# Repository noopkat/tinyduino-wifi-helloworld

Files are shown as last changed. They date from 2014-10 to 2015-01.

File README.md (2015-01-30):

tinyduino-wifi-helloworld
=========================

example IoT project for developers new to wifi driven hardware 

knoll

## Ok, whut.
This is just a quick project showing how simple it is to get up and running with the latest hotness - Internet of Thingy-ma-jiggers.

When all assembled and placed in a mailbox, it'll connect via wifi to both email and sms you when you get mail!

## I do not understand how.
In this example, I'm using an Arduino microprocessor teamed with a light sensor and a wifi module. A battery powers the Arduino, which constantly keeps track of how much light is in the mailbox. When the USPS dudette/dude opens the little back door to put your mail and parcels in, light streams into the mailbox. This trips the device, which will then connect to wifi and send the email and sms to you.

If you do not have one of those door opening mailboxes, you can program it the opposite way - put it in your mailbox so that the sensor gathers light from the mail slot, and when envelopes are pushed through it blocks the light momentarily. Effectively that will be the trigger.

Yep, this only works in daylight, but it's pretty cool anyway. YMMV with wifi strength if your mailbox is made of metal.

## Disclaimer
**This example is presented as educational only.**

Postal companies might not be too pleased about spotting a mysterious device in a mailbox. They won't always assume it's a perfectly harmless Internet of Thingy-ma-flippers contraption full of awesome. **I am not condoning breaking the law with this project. Make sure you're familar with mail/mailbox tampering laws in your country**. The U.S., for example, has a helpful PDF on mail security you can [view here](https://www.hsdl.org/?view&did=34409). Spoiler alert: it has serious people holding guns on the front cover. [This poster is also pretty amazing](https://about.usps.com/securing-the-mail/mailtampering.htm).

Long story short - don't scare the willies out of your friendly neighbourhood post deliverer. Nobody wants the SWAT outside their house.

## Shopping list
+ [TinyCircuits Processor board](https://tiny-circuits.com/tinyduino-processor-board.html)
+ [TinyCircuits Wifi module](https://tiny-circuits.com/tiny-shield-wifi.html)
+ [TinyCurcuits Proto module](https://tiny-circuits.com/tiny-shield-proto-board-2.html) (any will do)
+ [TinyCircuits USB programmer module](https://tiny-circuits.com/tiny-shield-usb-and-icp.html) (not pictured)
+ micro USB cable
+ 10k Ohm resistor
+ [photocell resistor](http://www.adafruit.com/products/161)
+ [3.7v LiPo battery](http://www.adafruit.com/products/1578), at least 500mA 

Tools I assume you have already:
+ [LiPo charger](http://www.adafruit.com/products/1304)
+ soldering iron
+ solder
+ good eyes (my eyes are terrible for close-up work like soldering, but I still manage okay)

## Assembly
[Read this, taken from my article in NDC Magazine](https://github.com/noopkat/tinyduino-wifi-helloworld/blob/master/article.md)

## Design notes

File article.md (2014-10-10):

# Using the Arduino platform to create your very own IoT devices
As a software developer, there's something magic about being able to say, "I made this myself!". Building hardware to integrate with software is no different. Sure, you can buy off the shelf IoT devices for your home and lifestyle, but there's much more fun in building your own. You'll learn a lot about how they work, and will take away a sense of pride and achievement.

This is just a quick project showing how simple it is to get up and running with building and programming your own Internet of Things devices.
When all assembled and placed in a mailbox, this contraption will connect via WiFi to both email and SMS you when you get mail!

In this example, I'm using an Arduino microprocessor teamed with a light sensor and a WiFi module. A battery powers the Arduino, which constantly keeps track of how much light is in the mailbox. When the postal delivery opens the little back door to put your mail and parcels in, light streams into the mailbox. This trips the device, which will then connect to WiFi and send the email and SMS to you.

If you do not have one of those door opening mailboxes, you can program it the opposite way - put it in your mailbox so that the sensor gathers light from the mail slot, and when envelopes are pushed through it blocks the light momentarily. Effectively that will be the trigger.

This only works in daylight, but it's pretty cool anyway. Your mileage may vary with WiFi strength if your mailbox is made of metal.

The full code is hosted on Github: https://github.com/noopkat/tinyduino-wifi-helloworld

**Warning**  - postal companies might not be too pleased about spotting a mysterious device in a mailbox. They won't always assume it's a perfectly harmless Internet of Things device. I am not condoning breaking the law with this project. Make sure you're familiar with mail/mailbox tampering laws in your country. Long story short - don't scare your friendly neighbourhood post deliverer. Nobody wants the police outside their house!

knoll of parts

## Shopping list
+ [TinyCircuits Processor board](https://tiny-circuits.com/tinyduino-processor-board.html)
+ [TinyCircuits Wifi module](https://tiny-circuits.com/tiny-shield-wifi.html)
+ [TinyCurcuits Proto module](https://tiny-circuits.com/tiny-shield-proto-board-2.html) (any will do)
+ [TinyCircuits USB programmer module](https://tiny-circuits.com/tiny-shield-usb-and-icp.html) (not pictured)
+ micro USB cable
+ 10k Ohm resistor
+ [photocell resistor](http://www.adafruit.com/products/161)
+ [3.7v LiPo battery](http://www.adafruit.com/products/1578), at least 500mA 

Tools I assume you have already:
+ [LiPo charger](http://www.adafruit.com/products/1304)
+ soldering iron
+ solder
+ good eyes (my eyes are terrible for close-up work like soldering, but I still manage okay)

## Assembly
My favourite feature of the TinyCircuits system (other than the tiny size) is the way they easily click together to supply the technology you need.
First, we're going to click everything together as we need it. 

Take the processor board, and click the USB module to the top of it. Then, click the WiFi module to the top of the USB one. Lastly, click together the proto board to the very top of the stack. This will be the order of the stack when we develop it. It allows us to power the board without a battery via the computer, and we can also program it this way.

Next, remove the proto module from the top of the stack. Solder the resistor and photocell to it. The resistor goes from A0 to GND, and the photocell shares the A0, and the other end goes to VBATT. VBATT is a special pin that makes both the USB and battery power sources available to use. See the breadboard fritzing diagram below to assist you:

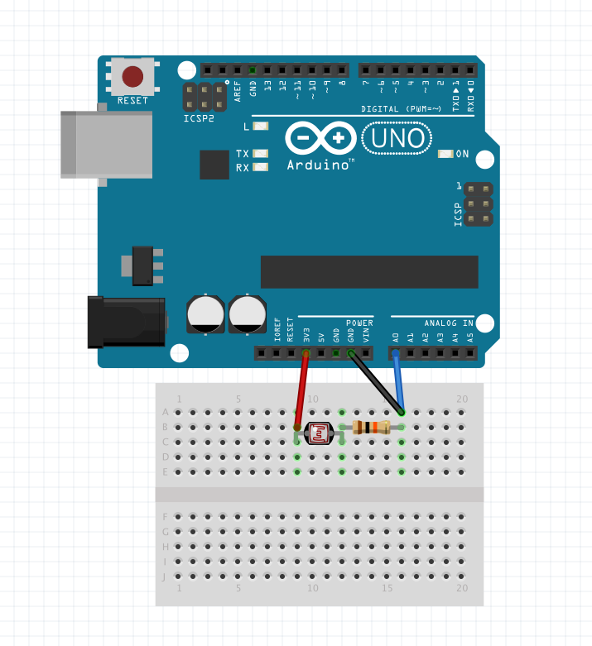
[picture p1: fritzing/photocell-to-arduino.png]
fritzing breadboard


See the following example for how it will look when complete. Note I have left the component arms rather long so that it's easier to see what's going on.

photo of stack

## Upload Arduino code
Click the proto module back onto your TinyCircuit stack. Plug a micro USB cable into the programming board, then connect to your computer. In the Arduino software, set the board to 'Arduino Pro Mini 3.3v w/ ATMega 328'. Open the sketch from the repo and click 'upload'. Select the correct USB device if prompted.

The main loop of the sketch is pretty simple, see the truncated code below:

```c++
uint32_t ip = cc3000.IP2U32(10,0,1,4);
int port = 8081;
String path = "/mailbox/token/";
String token = "558822";
String request = "GET " + path + token + " HTTP/1.0";

void loop(void)
{
  sensorValue = analogRead(sensorPin);
  // print to serial monitor for debugging purposes
  Serial.println(sensorValue);

  // if light source appears, set bright to true and send request
  // you may have the fiddle with this value to suit your light source
  if (sensorValue < 450 && bright == false) {
      // this will ensure request is sent only once
      bright = true;
      // send request to mailbox server
      send_request(request);
  } 

  // light source gone, go back to dark mode again
  if (sensorValue > 450 && bright == true) {
    bright = false;
  }
  
  delay(300);
}
```

You'll definitely need to play with the default light reading value set in the code above for best results with the physical place you're setting up your device in.

## Set up your server
I created a really simple NodeJS hapi server instance for dealing with the email and SMS. It is running on the local network the device is connected to via WiFi. The server simply waits for a GET request to the specified route, then verifies the request with a static token the Arduino will send as part of the request. This token should help stop your friends pranking you!

When the request is successful, the route handler will call some third party API's to send the notifications. I'm using Twilio for SMS, and Mailgun for the email.

A truncated sample of the code:

```javascript
var Hapi  = require('hapi');
var server = new Hapi.Server('10.0.1.4', 8081);
var passToken = '558822';

server.route({
    method: 'GET',
    path: '/mailbox/token/{token?}',
    handler: function (request, reply) {
      if (request.params.token && request.params.token === passToken) {
        // Twilio
        sendSMS();
        // MailGun
        sendEmail();
     // simple reply for testing manually
        reply('you\'ve got mail!');
      } else {
      // someone's being a prankster if missing/wrong token
        reply('why you gotta troll me, friend :(');
      }
    }
});
// Start the server
server.start();
```

Start the server in bash:

```
node index.js
```

## Test your device
While still plugged in to your computer, reset your device, and make sure your NodeJS server is running. To debug, watch both the Arduino app serial monitor's output, and your bash window. Play with the photo sensor, covering it up and then exposing it to light. You should start receiving emails and SMS's. 

Once verified, you can take the USB programming module out of your TinyCircuit stack completely, as we no longer need it. You'll see 2 terminals on the processor board. Solder a LiPo battery JST connector to these terminals in order to have this device run truly wire free and discreetly. Test again with the LiPo battery connected, then you're ready to use your finished device!

## Optional step
3D print a case for your new contraption, to make it look geek professional.

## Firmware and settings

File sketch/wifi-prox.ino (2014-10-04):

/* 
*  Tiny WiFi light sensor with a Tinyduino + CC3000 wifi module + photocell resistor
*  CC3000 lib written by Adafruit
*  sendRequest() method orginally written by Marco Schwartz for Open Home Automation
*  https://github.com/openhomeautomation/tiny-wifi-temperature/blob/master/tiny_weather_station/tiny_weather_station.ino
*  Further hacked by @noopkat for use with a light sensor, and a hard-set tokenised GET based on certain conditions, instead of constant reporting
*/

// Include required libraries
#include <Adafruit_CC3000.h>
#include <ccspi.h>
#include <SPI.h>
#include <string.h>
#include <stdlib.h>

// Define CC3000 chip pins
#define ADAFRUIT_CC3000_IRQ   2
#define ADAFRUIT_CC3000_VBAT  A3
#define ADAFRUIT_CC3000_CS    8

// WiFi network
#define WLAN_SSID       ""        // cannot be longer than 32 characters
#define WLAN_PASS       ""
#define WLAN_SECURITY   WLAN_SEC_WPA2 // This can be WLAN_SEC_UNSEC, WLAN_SEC_WEP, WLAN_SEC_WPA or WLAN_SEC_WPA2

// Create CC3000 instance
Adafruit_CC3000 cc3000 = Adafruit_CC3000(ADAFRUIT_CC3000_CS, ADAFRUIT_CC3000_IRQ, ADAFRUIT_CC3000_VBAT, SPI_CLOCK_DIV2);
                                         
// Local server IP, port, and repository (replace these with your own server setup)
uint32_t ip = cc3000.IP2U32(10,0,1,4);
int port = 8081;
String path = "/mailbox/token/";
String token = "558822";

// this is the api call (minus ip and port) to your software running anywhere
// token is just a little verification to prevent terrible friends just hitting your service to troll you with false positives
String request = "GET " + path + token + " HTTP/1.0";

int sensorPin = A0;
// set to dark to begin with
int sensorValue = 1023;
bool bright = false;


void setup(void)
{
  // Start serial
  Serial.begin(9600);
    
  // Initialise the CC3000 module
  if (!cc3000.begin())
  {
    while(1);
  }
}

void loop(void)
{
  sensorValue = analogRead(sensorPin);
  Serial.println(sensorValue);

  // if light source appears, set bright to true and send request
  if (sensorValue < 450 && bright == false) {
      // this will ensure request is sent only once
      bright = true;
      // connect to WIFI
      connect_wifi();
      // hit up mailbox server
      send_request(request);
      // disconnect to save battery
      cc3000.disconnect();
  } 

  // light source gone, go back to dark mode again
  if (sensorValue > 450 && bright == true) {
    bright = false;
  }
  
  delay(300);
}

void connect_wifi() {
  // Connect to  WiFi network
  cc3000.connectToAP(WLAN_SSID, WLAN_PASS, WLAN_SECURITY);
  Serial.println("Connected to WiFi network!");
    
  // Check DHCP
  Serial.println(F("Request DHCP"));
  while (!cc3000.checkDHCP())
  {
    delay(100);
  }  
}

// Function to send a TCP request and get the result as a string
void send_request(String request) {
     
  // Connect    
  Serial.println("Starting connection to server...");
  Adafruit_CC3000_Client client = cc3000.connectTCP(ip, port);
  
  // Send request
  if (client.connected()) {
    client.println(request);      
    client.println(F(""));
    Serial.println("Connected & Data sent");
  } 
  else {
    Serial.println(F("Connection failed"));    
  }

  while (client.connected()) {
    while (client.available()) {

    // Read answer
    char c = client.read();
    }
  }
  Serial.println("Closing connection");
  Serial.println("");
  client.close();    
  Serial.println("Connection closed.");
}

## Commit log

2014-10-03 add fritzing
    [photocell-to-arduino.fzz]
2014-10-04 edit fritz, disconnect on send request, twilio and mailgun cleanup
    [photocell-to-arduino.fzz]
2014-10-04 update fritzing
    [photocell-to-arduino.fzz]
2014-10-06 neatened fritzing
    [photocell-to-arduino.fzz]
